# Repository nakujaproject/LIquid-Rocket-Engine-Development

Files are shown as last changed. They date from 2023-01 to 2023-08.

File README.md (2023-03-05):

Title

This repository contains work done in addition to work done previously on the liquid rocket engine during the internship period of 2023 by the liquid propulsion team.

## Milestones
so far, the following has been achieved previously:
- [x] Design of components
- [x] Fabrication of components
- [x] assembly of engine, pintle injector & test stand to run the setup
- [x] Demonstrations (Seperately).

## ToDo
next up, our goals are:
- [] completion of test stand for fuel and oxidizer supply
- [] water test (low pressure)
- [] water test (high pressure tests)
- [] ignition test

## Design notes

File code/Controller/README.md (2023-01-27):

# Introduction
This repository holds the code that allows for and shows proof for dynamic regenerative cooling in a liquid rocket engine.

# Working
The proof is shown by turing on the heater for a certain amount of time and running the coolant at one base flow rate that keeps the temperature constant. A rise in the heater temperature should result in an increase in flow rate to keep the temperature within the same desired window.

The user, through our UI, inputs the desired temperature window and the system computes the required coolant flow rate depending on the current sensor readings.

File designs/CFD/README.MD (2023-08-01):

# This directorycontains files for ansys fluent CFD simulation done on the ignitor for the liquid rocket engine.

The 3-D model for the ASI is as shown below:
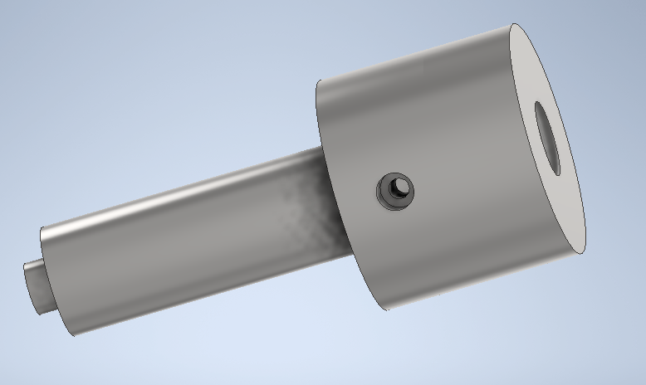
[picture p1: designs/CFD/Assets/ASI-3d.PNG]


The scaled residuals obtained from simulaton. (Note: you may have to rerun the simulation to get your desired result or replicate the existing ones)
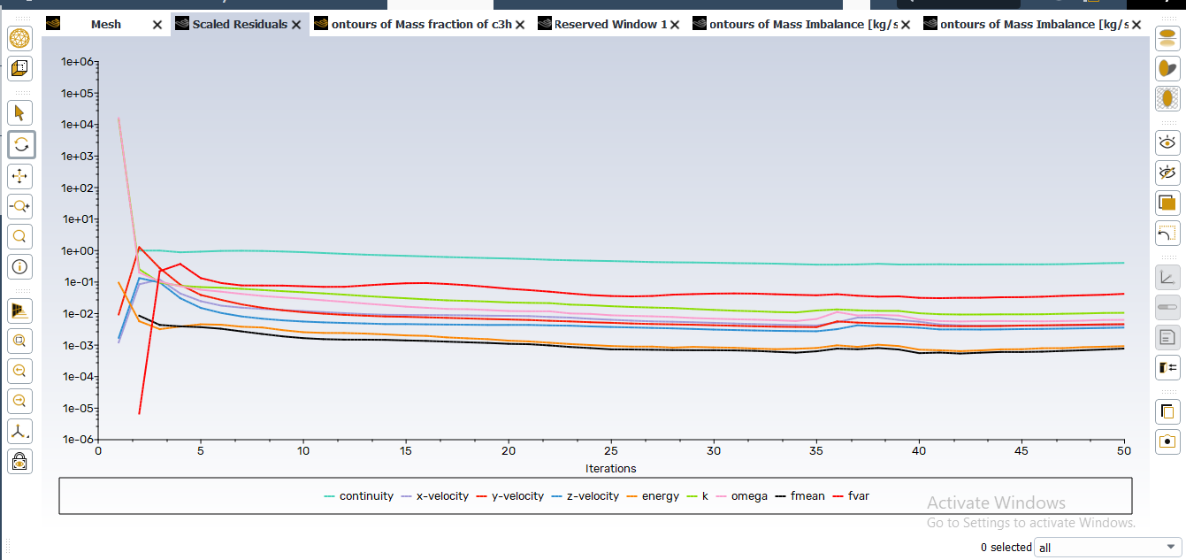
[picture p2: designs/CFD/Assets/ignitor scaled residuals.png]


the following were the models from which a subtractive boolean cut was made. The tool body used is as shown:
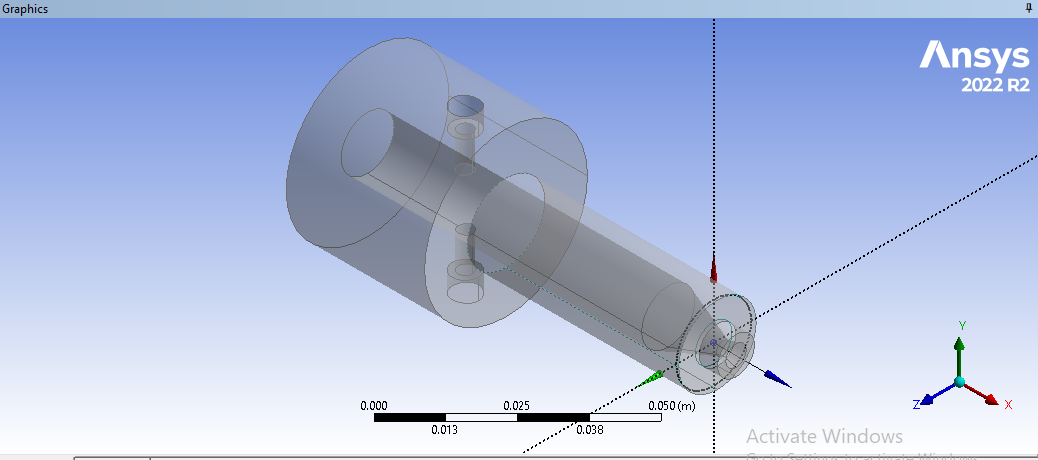
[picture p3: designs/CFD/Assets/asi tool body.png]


and for the target body as shown:
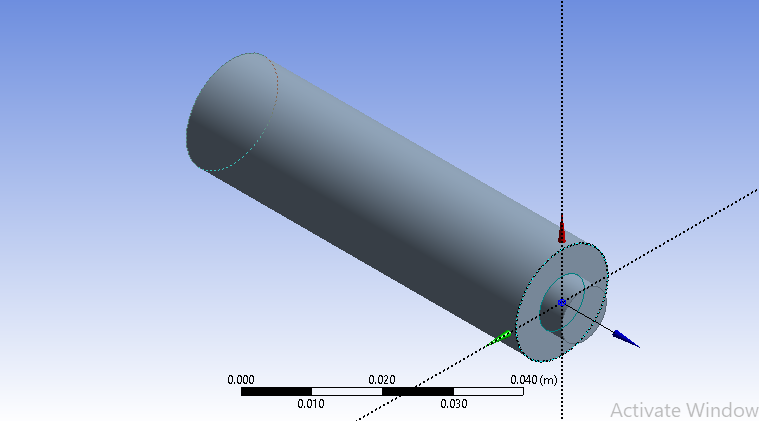
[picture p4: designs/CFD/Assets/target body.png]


the meshing produced by the Ansys meshing software is as shown:
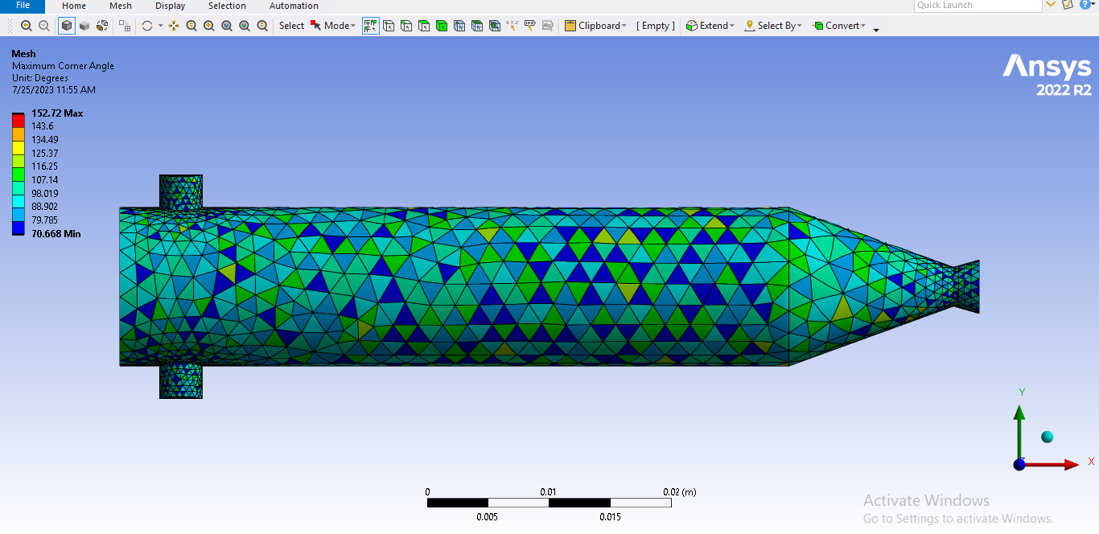
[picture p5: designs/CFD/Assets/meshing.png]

this may help in editing the mesh for simulation

while the same mesh as displayed within fluent simulation environment is shown:
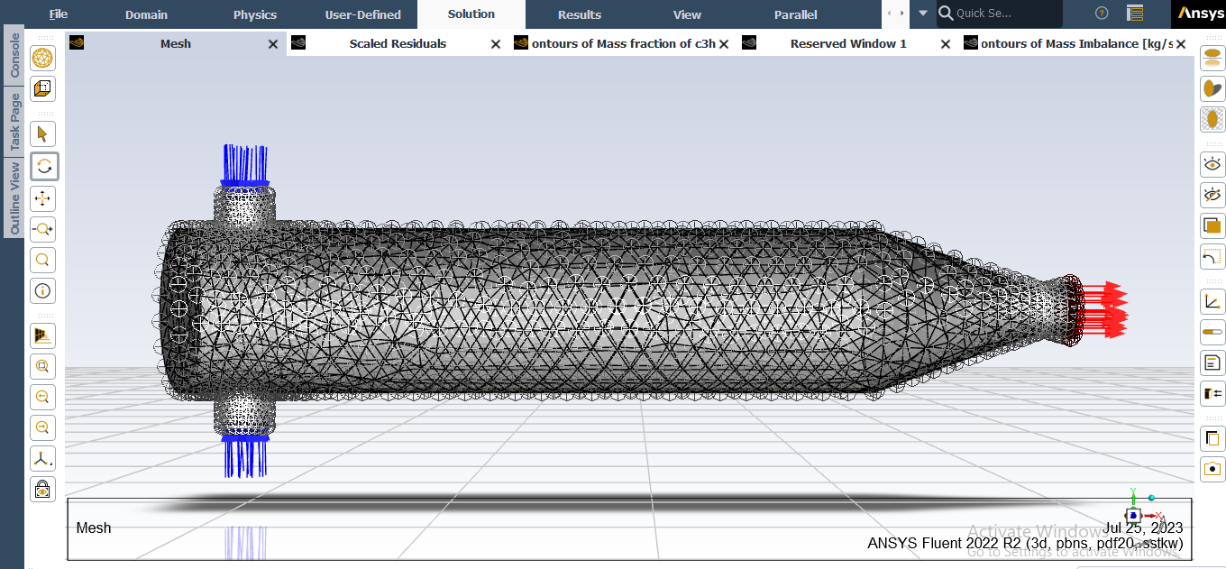
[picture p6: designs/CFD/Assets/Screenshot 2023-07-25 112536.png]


one inlet is for propane and the other for oxygen

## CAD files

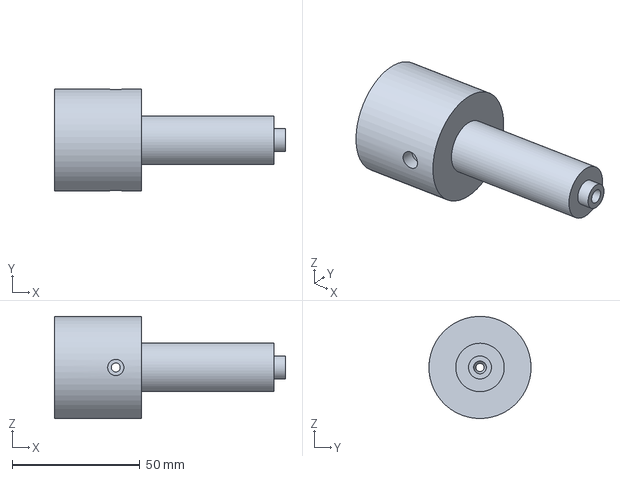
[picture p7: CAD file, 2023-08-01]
designs/CFD/ASI Propane v1.step
90.5 x 40.0 x 40.0 mm

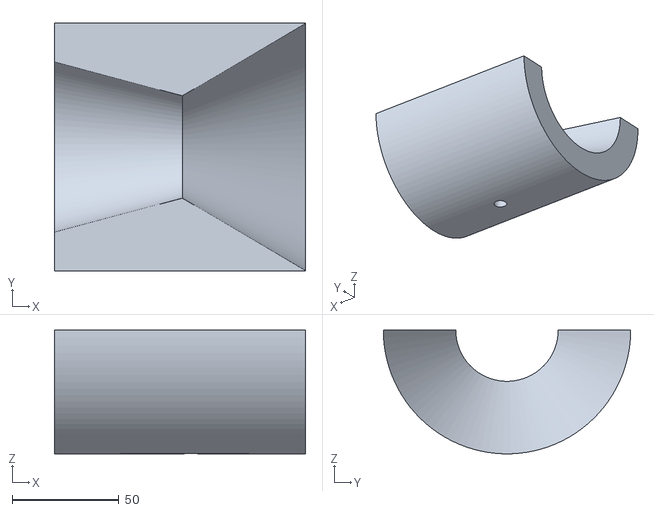
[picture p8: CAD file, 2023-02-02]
designs/Spacer_V23 v1.stl
117.6 x 116.0 x 58.0

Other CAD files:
Stainless arrangement.iam
designs/LRE assembled_2.f3z

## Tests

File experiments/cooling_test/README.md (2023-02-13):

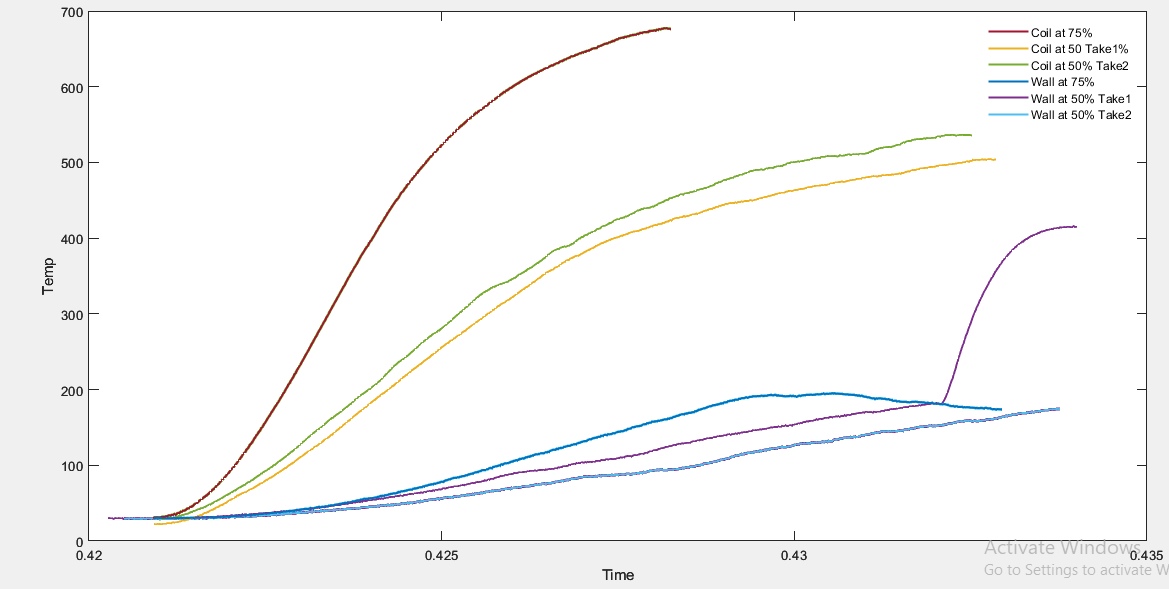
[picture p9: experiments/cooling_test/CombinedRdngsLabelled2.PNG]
Cooling Test Curve


## Description
Below are the graphs of the temperature comparisons of the coil vs the outside of the chamber walls.
We heated the coil at 2 different rates; ~50% and ~75%.

The graphs show that the temperature of the outside wall is about 30% of the inside temperature. Eg. The wall temperature was barely 200°C when the coil temperature was 670°C.

These are 6 curves.

The 1st curve represents the coil temperature with 75% heating rate.
The next 2 curves represent the coil temp with 50% heating rate.
The last 3 curves represent the outside wall temperatures, the top being with 75% and the other two with 50%.

A second finding is that the outside temperature doesn't change spontaneously with the coil temperature. We can see the 3 outside wall temperatures are about the same.

## ToDo

However, they are all well above the boiling point of water, thus we'll see how to go about that challenge when we conduct the water test.

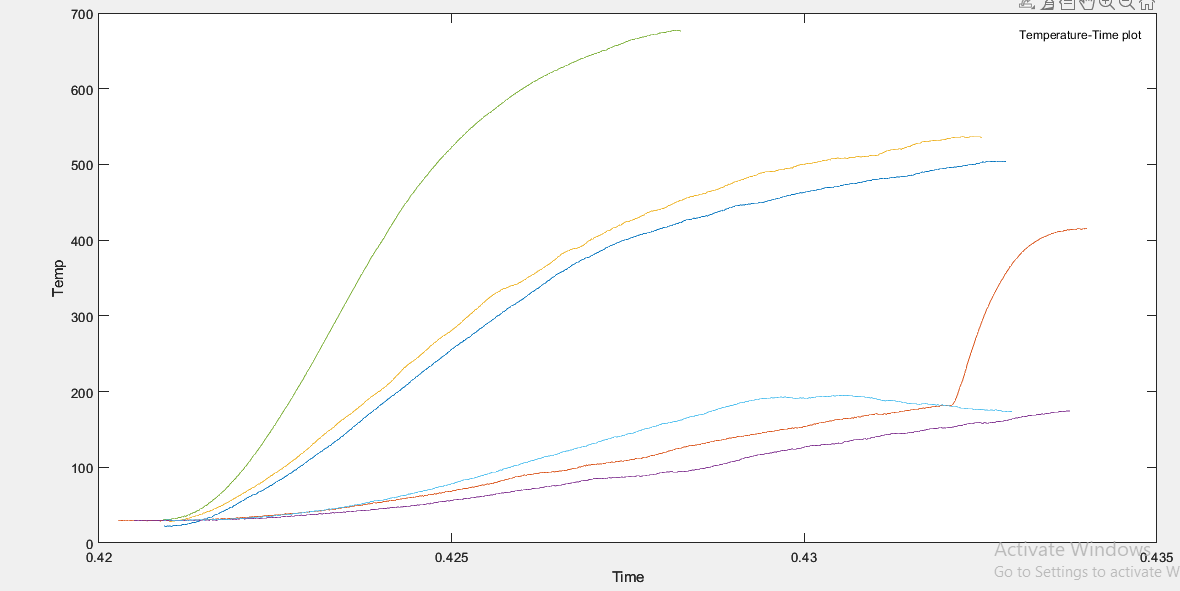
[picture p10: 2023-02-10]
experiments/cooling_test/CombinedRdngs.PNG

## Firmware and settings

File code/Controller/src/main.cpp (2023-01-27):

#include <Arduino.h>
#include <Wire.h>
#include <string.h>
#include "OneWire.h"
#include "DallasTemperature.h"
#include "max6675.h"
#include "LiquidCrystal_I2C.h"
#include "defs.h"
#include "Keypad.h"


// Objects
MAX6675 thermocouple(sckPin, csPin, soPin); // create instance object of MAX6675
Keypad keypad = Keypad(makeKeymap(hexaKeys), rowPins, colPins, ROWS, COLS);
LiquidCrystal_I2C lcd(0x27, 20, 4);

// function prototypes
bool tests();
bool lcdTest();
bool thermocoupleTest();
void print_lcd(float temp1, float temp2, float temp3, float flowrate);
void runPump();
void turnOnHeater();
void turnOffHeater();
void turnOnFan();
void turnOffFan();
void checkflowrate();
void increaseFlowrate();
void keypadEvent(KeypadEvent key);

unsigned long lastBlink =0;

// for automation of circuit
int pinInput = 2; // Assign the pin input to a variable
// int flagValue = 0;


int triac_delay = 2500;
int constrained_triac_delay = constrain(triac_delay, 0, 5000);
short int pump_flag = 0;

float thermocoupleTemp = 0.0;
float lastReadThermocouple = 0.0;
float lastContThermocouple = 0.0;

short int temp_change_flag = 0;
float flowrate =0.0;

int initial_time;
int current_time;

int f_prev_time = 0;
int f_current_time = 0;

int prev_temp_time = 0;
int current_temp_time;

int prev_time;
int var1 = 0;
int init_const_time_flag = 0;
int init_dyn_time_flag = 0;



int fx;
int fy;
float ftime;
float f_frequency;
float ftotal;
float f_flm;
float f_fls;
float f_flh;


void setup(void)
{

  Serial.begin(115200);
 // keypad.addEventListener(keypadEvent);
  turnOffFan();
  pinMode(pinInput, INPUT); // Set the pin to input mode
  pinMode(ZERO_CROSS_PIN, INPUT);
  pinMode(PUMP_PIN, OUTPUT);
  pinMode(HEATER_PIN, OUTPUT);
  pinMode(WHITE_LED, OUTPUT);
  pinMode(GREEN_LED, OUTPUT);
  pinMode(FAN_PIN, OUTPUT);
  pinMode(FLOWRATE_PIN,INPUT);
  pinMode(PC13,OUTPUT);
  //digitalWrite(PC13,LOW);
  
  while(!tests())
  {
    if(millis()-lastBlink >= 500)
    {
      digitalWrite(WHITE_LED,!digitalRead(WHITE_LED));
      lastBlink =millis();
    }
  };

  delay(setup_time);
  attachInterrupt(ZERO_CROSS_PIN, runPump, CHANGE);
  prev_time = millis();
}




void loop(void)
{
  // input from aduino mega
  int pinState = digitalRead(pinInput);

  if (pinState == HIGH) {
    thermocoupleTemp = thermocouple.readCelsius();
    f_current_time = millis();
    if(f_current_time - f_prev_time >= 1000)
    {
      checkflowrate();
      f_prev_time = f_current_time;
    }
    //Serial.println(f_flm);
    Serial.println(constrained_triac_delay);
    char key = keypad.getKey();
    //Serial.println(key);
    switch(var1){
      case 0:
        pump_flag = 0;
        init_const_time_flag = 0;
        init_dyn_time_flag = 0;
        lcd.clear();
        lcd.setCursor(0,0);
        lcd.print("I_STATE   ");
        lcd.print("LCT: ");
        lcd.print(lastContThermocouple);
        lcd.setCursor(0,1);
        lcd.print("Temp: ");
        lcd.print(thermocoupleTemp);
        lcd.print("deg");
        lcd.setCursor(0,2);
        lcd.print("Q: ");
        lcd.print(f_flm);
        lcd.print(" l/m");
        lcd.setCursor(0,3);
        lcd.print("CTEST: 1 :: DTEST: 2");
        turnOffFan();
        if(key == '1')
        {
          var1 = 1;
        }
        if(key == '2')
        {
          var1 = 2;
        }
        // if(keypad_pressed)
        // {
          //   var1 = 2;
          // }
        break;
      case 1:
        turnOnFan();
        lcd.clear();
        lcd.setCursor(0,0);
        lcd.print("C_STATE  ");
        lcd.print("LCT: ");
        lcd.print(lastContThermocouple);
        lcd.setCursor(0,1);
        lcd.print("Temp: ");
        lcd.print(thermocoupleTemp);
        lcd.print("deg");
        lcd.setCursor(0,2);
        lcd.print("Q: ");
        lcd.print(f_flm);
        lcd.print(" l/m");
        lcd.setCursor(0,3);
        lcd.print("CANCEL: C");
        if(init_const_time_flag == 0)
        {
          initial_time = millis();
          init_const_time_flag = 1;
        }
        triac_delay = 2500;
        constrained_triac_delay = constrain(triac_delay, 0, 5000);
        current_time = millis();
        if(current_time - initial_time <= 110000)
        {
          pump_flag = 1;
          if((current_time - initial_time >= 20000) && (current_time - initial_time <= 50000))
          {
            turnOnHeater();
            }
          else
          {
            turnOffHeater();
            }
        }
        else
        {
          pump_flag = 0; //pump off
          var1 = 0; //will go to case 0
          lastContThermocouple = thermocoupleTemp; 
        }
        if(key == 'C')
        {
          var1 = 0;
        }
        break;
        
      case 2:
        turnOnFan();
        lcd.clear();
        lcd.setCursor(0,0);
        lcd.print("D_STATE  ");
        lcd.print("LCT: ");
        lcd.print(lastContThermocouple);
        lcd.setCursor(0,1);
        lcd.print("Temp: ");
        lcd.print(thermocoupleTemp);
        lcd.print("deg");
        lcd.setCursor(0,2);
        lcd.print("Q: ");
        lcd.print(f_flm);
        lcd.print(" l/m");
        lcd.setCursor(0,3);
        lcd.print("CANCEL: C");
        if(init_dyn_time_flag == 0)
        {
          initial_time = millis();
          init_dyn_time_flag = 1;
        }
        current_time = millis();
        if((current_time - initial_time <= 110000))
        {
          pump_flag = 1;
          if(current_time - initial_time >= 20000)
          {
            if(current_time - initial_time <= 50000)
            {
              turnOnHeater();
            }
            else
            {
              turnOffHeater();
            }
            current_temp_time = millis();
            if(current_temp_time - prev_temp_time >= 3000)
            {
              lastReadThermocouple = thermocoupleTemp;
              prev_temp_time = current_temp_time;
            }
            if(thermocoupleTemp - lastReadThermocouple >=0.2)
            {
              increaseFlowrate();
            }
          }
        }
        else
        {
          pump_flag = 0;
          var1 = 0;
          lastContThermocouple = thermocoupleTemp;
        }
        if(key == 'C')
        {
          var1 = 0;
        }
        break;
        default:
        var1 = 0;
        break;
    }
    // if (temp_change_flag == 0)
    // {
    //   thermocoupleTemp += 1;
    //   if(thermocoupleTemp >=25)
    //   {
    //     temp_change_flag = 1;
    //   }
    // }
    // else
    // {
    //   thermocoupleTemp -= 1;
    //   if(thermocoupleTemp <=0)
    //   {
    //     temp_change_flag = 0;
    //   }
    // }
  
    // Serial.print("Thermocouple temp = ");
    // Serial.println(thermocoupleTemp);
    // Serial.print("Last Thermocouple temp = ");
    // Serial.println(lastReadThermocouple);
    // Serial.print("Triac delay is: ");
    // Serial.println(constrained_triac_delay);
    //current_time = millis();
  }
  else{
    // do nothing.
  }
}

bool tests(){
  while (!lcdTest())
  { //we'll see wht will go here
  }
  while (!thermocoupleTest())
  {  // for here too
  }
  return true;
  }

bool lcdTest(){
  lcd.init();
  lcd.backlight();
  lcd.print("Maya v0.0.2");
  lcd.setCursor(7, 3);
  lcd.print("internship-2023");
  delay(1000);
  lcd.clear();
  lcd.print("Starting tests ........");
  delay(1000);
  return true;
}

bool thermocoupleTest(){
  lcd.clear();
  lcd.print("Running thermocouple test!!!!");
  int count = 0;
  while (count < 10)
  {
    delay(100);
    if (thermocouple.readCelsius() > 0 && thermocouple.readCelsius() < 50)
    {
      count++;
    }
    else
    {
      continue;
    }
  }
  lcd.clear();
  lcd.println("Thermocouple test complete !!!!!!");
  delay(1000);
  return true;
}

void print_lcd(float temp1, float temp2, float temp3, float flowrate){
  lcd.clear();
  lcd.setCursor(0, 0);
  lcd.print("Thermocouple: ");
  lcd.print(temp1);
  lcd.setCursor(0, 1);
  lcd.print("Probe 1: ");
  lcd.print(temp2);
  lcd.setCursor(0, 2);
  lcd.print("Probe 2: ");
  lcd.print(temp3);
  lcd.setCursor(0,3);
  lcd.print("Flowrate:");
  lcd.print(flowrate);
  lcd.print("L/m");
}

/**
 * @brief function to increase flowrate according to temperature
 */
void increaseFlowrate(){
  // implement increased flowrate
  triac_delay -= 500;
  constrained_triac_delay = constrain(triac_delay, 0, 5000);
}
  
/**
 * * @brief function to decrease flowrate.
 * */
void decreaseFlowrate()
{
  triac_delay += 500;
  constrained_triac_delay = constrain(triac_delay, 0, 5000);
}
  
/**
 * * @brief function to run the pump.
 * */
void runPump(){
  // TO IMPLEMENT RUN PUMP
  if(pump_flag == 0)
  {
    digitalWrite(PUMP_PIN, LOW);
  }
  else
  {
    delayMicroseconds(constrained_triac_delay);
    digitalWrite(PUMP_PIN, HIGH);
    delayMicroseconds(10);
    digitalWrite(PUMP_PIN, LOW);
  }
}
  
void checkflowrate(){
  fx = pulseIn(FLOWRATE_PIN, HIGH);
  fy = pulseIn(FLOWRATE_PIN, LOW);
  ftime = fx + fy;
  f_frequency = 1000000/ftime;
  f_flm = f_frequency/7.5;
  f_fls = f_flm/60.0;
  f_flh = f_flm*60;
}
  
/**
 * * @brief function to turn on the heater
 * */
void turnOnHeater(){
  digitalWrite(HEATER_PIN, HIGH);
}
  
/**
 * * @brief function to turn off the heater
 * */
void turnOffHeater()
{
  digitalWrite(HEATER_PIN, LOW);
}
  
/**
 * * @brief Function to turn on the fan
 * */
void turnOnFan(){
  digitalWrite(FAN_PIN, LOW);
}
  
/**
 * * @brief Function to turn the fan off
 * * */
void turnOffFan(){
  digitalWrite(FAN_PIN, HIGH);
}

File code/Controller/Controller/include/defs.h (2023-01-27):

#ifndef PIN_DEFINITIONS_H
#define PIN_DEFINITIONS_H


#define soPin PA6  // SO=Serial Out
#define csPin PA7  // CS = chip select CS pin
#define sckPin PA5 // SCK = Serial Clock pi
#define ONE_WIRE_0 PB12 // One Wire Probe 1
#define ONE_WIRE_1 PB13 // One wire Probe 2

#define MAX_WALL_TEMP 400.0
#define MAX_TEMP_DIFF 5.0
#define CONTROL_TEMP_VALUE 200.0


#define PUMP_PIN PB14
#define ZERO_CROSS_PIN PB8
#define HEATER_PIN PB10
#define FAN_PIN PB4
#define GREEN_LED PB15
#define WHITE_LED PA9


#endif

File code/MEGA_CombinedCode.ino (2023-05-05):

#include <ArduinoJson.h>

const int pressurePin_GN2 = A0; // 10V Sensor
const int pressurePin_GOX = A1; // 10V Sensor
const int pressurePin_3 = A2; // 5V Sensor
const int pressurePin_4 = A3; // 5V Sensor
const int pressurePin_5 = A4; // 5V Sensor
int sv_readPin = A7; // Used to test the 3 SVs using the voltage divider circuit. Value range 30<x<75 for the curcuit

int flowPin_FUEL = 2;
int flowPin_GN2 = 3;
int flowPin_GOX = 18;
// Arduino Nano interrupt pins are only 2 & 3.
// Arduino Mega interrupt pins are 2,3,18,19,20,21 (20&21 aren't available to use for interrupts when being used for I2C communication

int svPin_FUEL = 6;
int svPin_GN2 = 7;
int svPin_GOX = 8;

// Variables
int SerialInt; // Serial input from ESP32 to Mega

int samplingFrequency_Hz = 2000; // 2000Hz(2KHz) translates to Period of 0.5ms (0.0005s)

int samplingPeriod_ms = 1000/samplingFrequency; // 0.5ms -> 2KHz (This is a stable rate to loop the sensors. Higher f gives less accurate Q values)
float flowrateFUEL, flowrateGN2, flowrateGOX, amountFUEL, amountGN2, amountGOX;
float pressureVal_GN2, pressureVal_GOX, pressureVal_3, pressureVal_4, pressureVal_5;
float pressureGN2, pressureGOX, pressure3, pressure4, pressure5;
int Int_SolenoidState = 0;

volatile long pulseFUEL, pulseGN2, pulseGOX;
long int signalFUEL, signalGN2, signalGOX;
long int lastpulseFUEL, lastpulseGN2, lastpulseGOX;
unsigned long currentTime = 0;
unsigned long lastTime1 = 0;
unsigned long lastTime2 = 0;

// Boolean Variables for Sensor Test code
bool PressTotalBool=false; bool FlowTotalBool=false; bool SVTotalBool=false; bool FinalBool=false;
bool TestBool=false; // Will be turned to true to run the sensor test functions
bool GetDataBool=false; // Will be turned to true to run the sensor test functions

void setup() {
  Serial.begin(9600);

  pinMode(LED_BUILTIN, OUTPUT);
  
  pinMode(pressurePin_GN2, INPUT);
  pinMode(pressurePin_GOX, INPUT);
  pinMode(pressurePin_3, INPUT); // INPUT_PULLUP gives some errors. It raises the 1bar from 100 to 120. Probably Sensor has internal resistance.
  pinMode(pressurePin_4, INPUT);
  pinMode(pressurePin_5, INPUT);
  pinMode(sv_readPin, INPUT);
  
  pinMode(flowPin_FUEL, INPUT);
  pinMode(flowPin_GN2, INPUT);
  pinMode(flowPin_GOX, INPUT);

  pinMode(LED_BUILTIN, OUTPUT);
  pinMode(svPin_FUEL, OUTPUT);
  pinMode(svPin_GN2, OUTPUT);
  pinMode(svPin_GOX, OUTPUT);
  
  attachInterrupt(digitalPinToInterrupt(flowPin_FUEL), Function_increasePulseFUEL, RISING);
  attachInterrupt(digitalPinToInterrupt(flowPin_GN2), Function_increasePulseGN2, RISING);
  attachInterrupt(digitalPinToInterrupt(flowPin_GOX), Function_increasePulseGOX, RISING);

  Serial.println("Ready: ");
  Serial.println();
}


void loop() {
  if(Serial.available()>0){
    SerialInt = Serial.parseInt(SKIP_ALL, '\n');

    // Ensure MEGA is working
    if(SerialInt==0){
      // Create a JSON object
      StaticJsonDocument<30> doc;
      doc["MEGA State"] = true;       
      // Serialize the JSON object to a string and send it over serial
      String jsonStr;
      serializeJson(doc, jsonStr);Serial.println(jsonStr);Serial.println();
      
    }

    // Run Sensor Test Code
    else if(SerialInt==123){
      TestBool=true;
      SensorsTest();
      
      StaticJsonDocument<15> doc;
      doc["FinalBool"] = FinalBool;
      String jsonStr;
      serializeJson(doc, jsonStr);Serial.println(jsonStr);Serial.println();
      TestBool=false;
      
    }
    
    // Get sensor data
    else if(SerialInt==456){
      GetDataBool=true;
    }

    // Stop getting sensor data
    else if(SerialInt==789){
      digitalWrite(LED_BUILTIN, LOW);
      GetDataBool=false;
    }
    
    // Control SVs
    else if(SerialInt>=0 && SerialInt<=7){
      Function_solenoids(SerialInt);
    }
    else{
      Serial.println("Invalid command.");
    }    
  }

  if(GetDataBool==true){
    SensorData();
      
    // Create a JSON object
    StaticJsonDocument<150> doc;
    doc["SVState"] = Int_SolenoidState;
    doc["Q FUEL"] = flowrateFUEL; // amountFUEL; // flowrateFUEL
    doc["Q GN2"] = flowrateGN2;
    doc["Q GOX"] = flowrateGOX;
    doc["P GN2"] = pressureGN2;
    doc["P GOX"] = pressureGOX;
    doc["P 3"] = pressure3;
    doc["P 4"] = pressure4;
    doc["P 5"] = pressure5;
    // Serialize the JSON object to a string and send it over serial
    String jsonStr;
    serializeJson(doc, jsonStr);
    Serial.println(jsonStr);
    Serial.println();
  }
}




//---------------------------------   FUNCTIONS   -------------------------------------------------------------------------------------------


// *****************************************************************************************
//                                         1 A. SENSORS TEST
// 1. Compilation of the 3 sensor test functions. This function is called at the loop.
int SensorsTest(){
  int x=0;
  FlowTotalBool=false; PressTotalBool=false; SVTotalBool=false; FinalBool=false;
  
  while(x<3 && FinalBool!=true){ // x<5 && FinalBool!=true
    if((millis() - lastTime1) >= samplingPeriod_ms){
      
      if(FlowTotalBool!=true){Function_flowmeters(pulseFUEL, pulseGN2, pulseGOX);}
      if(PressTotalBool!=true){Function_pressures();}
      if(SVTotalBool!=true){Test_SolenoidValves();}
      
      x++;
      lastTime1 = millis();
    }   
    
    if(FlowTotalBool==true && PressTotalBool==true && SVTotalBool==true){ //  FlowTotalBool==true && PressTotalBool==true && SVTotalBool==true
      FinalBool=true;
      TestBool=false;
    }
    if(x>2 && FinalBool!=true){
      Serial.println("Sensor Test aborted after 3 Tests. Faulty sensor(s)");
    }
  }
}


// ****************************************************************************************************
//                                          1 B. SENSORS DATA
//
int SensorData(){
  if((millis()-lastTime2) >= samplingPeriod_ms){
    digitalWrite(LED_BUILTIN, HIGH);
    
    Function_flowmeters(pulseFUEL, pulseGN2, pulseGOX);
    Function_pressures();

    lastTime2 = millis();
  }else{
    digitalWrite(LED_BUILTIN, LOW);
  }
}



// *****************************************************************************************************
//                                      2 A. FLOW SENSORS
// 1. Pulse increase upon interrupts
void Function_increasePulseFUEL(){
  pulseFUEL++;}
void Function_increasePulseGN2(){
  pulseGN2++;}
void Function_increasePulseGOX(){
  pulseGOX++;}
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

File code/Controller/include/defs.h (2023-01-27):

#ifndef PIN_DEFINITIONS_H
#define PIN_DEFINITIONS_H

#include <Arduino.h>

#define soPin PA6  // SO=Serial Out
#define csPin PA7  // CS = chip select CS pin
#define sckPin PA5 // SCK = Serial Clock pi
#define ONE_WIRE_0 PB12 // One Wire Probe 1
#define ONE_WIRE_1 PB13 // One wire Probe 2

#define MAX_WALL_TEMP 400.0
#define MAX_TEMP_DIFF 5.0
#define CONTROL_TEMP_VALUE 20.0

#define ONBOARD_LED PC13
#define FLOWRATE_PIN PB3
#define PUMP_PIN PB14
#define ZERO_CROSS_PIN PB8
#define HEATER_PIN PB10
#define FAN_PIN PB4
#define GREEN_LED PB15
#define WHITE_LED PA9
#define setup_time 5000

const byte ROWS = 4; //four rows
const byte COLS = 4; //three columns
char hexaKeys[ROWS][COLS] = {
  {'1','2','3','A'},
  {'4','5','6','B'},
  {'7','8','9','C'},
  {'*','0','#','D'}
};

byte rowPins[ROWS] = {PA0, PA2, PA3, PA4}; //connect to the row pinouts of the keypad
byte colPins[COLS] = {PB9, PC13, PC14, PC15}; //connect to the column pinouts of the keypad


#endif

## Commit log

2023-02-02 added spacer model
    [Spacer_V23 v1.stl]
2023-03-05 esp32_client -> influxdbclient
2023-04-18 independent run for esp32
2023-04-26 Create SensorTest
2023-07-01 engine supports
    The stainless steel arrangement of cut sheet metal
    [Stainless arrangement.iam]
2023-07-10 assembled liquid rocket engine
    [LRE assembled_2.f3z]
2023-07-15 inventor cad files
2023-08-01 CFD files
    [ASI Propane v1.step]
